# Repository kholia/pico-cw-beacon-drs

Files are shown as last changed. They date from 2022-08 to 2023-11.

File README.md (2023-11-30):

#### Details

This project generates a RF signal by toggling a GPIO pin (of a Raspberry Pi
Pico / Pico W board) at a high speed (HF frequency).

Note: The default GPIO pin is `GP2`.

#### Build Steps

Note: This repository has pre-built firmware files in it (`*.uf2` files) for
testing, and debugging purposes.

The following steps demonstrate the process of re-building the firmware from
the source code.

Common steps:

```
sudo apt install cmake gcc-arm-none-eabi libnewlib-arm-none-eabi \
    libstdc++-arm-none-eabi-newlib

sudo apt install gqrx-sdr fldigi pavucontrol pavucontrol-qt pamix
```

```
./build.sh
```

#### Customizations

To customize the CW message, CW speed, and the message, please edit the
`blink.pio` and `message.h` files.

- CW beacon message can be changed in `message.h` file.

- WPM can be changed in `blink.pio` file.

  ```
  // https://www.codebug.org.uk/learn/step/541/morse-code-timing-rules/
  int dit_delay = 92; // 13 WPM
  ```

- RF frequency can be changed in `blink.pio` file.

  The default value targets the 30m band amateur radio band.

Note: Whenever you change these files, please run the following command to
build the firmware file(s).

```
./build_again.sh
```

#### Usage

Write `pio_blink_pico.uf2` to the Raspberry Pi Pico board OR write
`pio_blink_pico_w.uf2` to the Raspberry Pi Pico W board.

To do so, press the BOOTSEL button and hold it while you connect the other end
of the micro USB cable to your computer. This puts your Raspberry Pi Pico into
USB mass storage device mode. Drag and drop the appropriate .uf2 file to the
`Pico` drive.

Attach picocom or another serial terminal program to `/dev/ttyACM0` (typically)
for added fun.

https://projects.raspberrypi.org/en/projects/getting-started-with-the-pico has
additional details on this process.

Monitor the lower 30m or 144 MHz (2m) band using a SDR for receiving the CW
beacon.

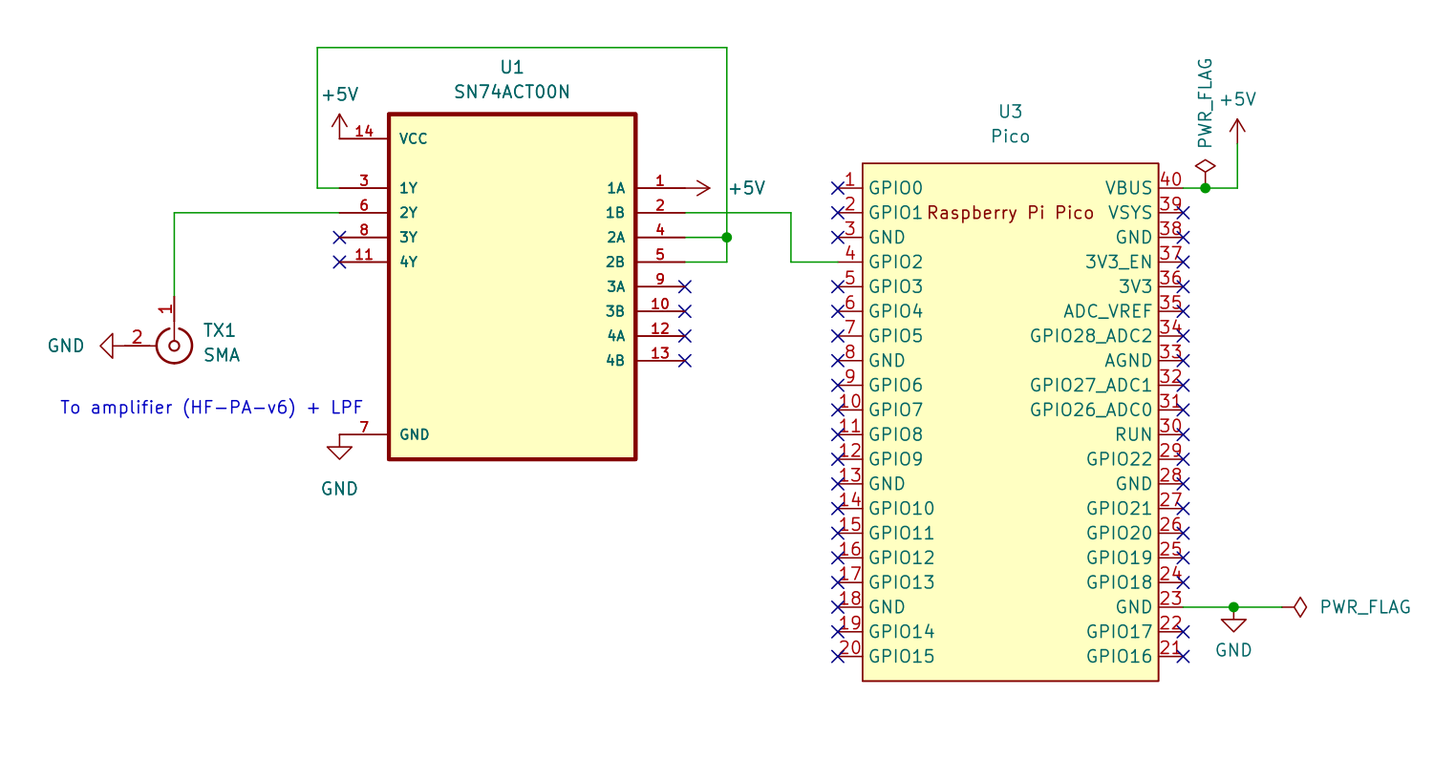
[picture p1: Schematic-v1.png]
Schematic


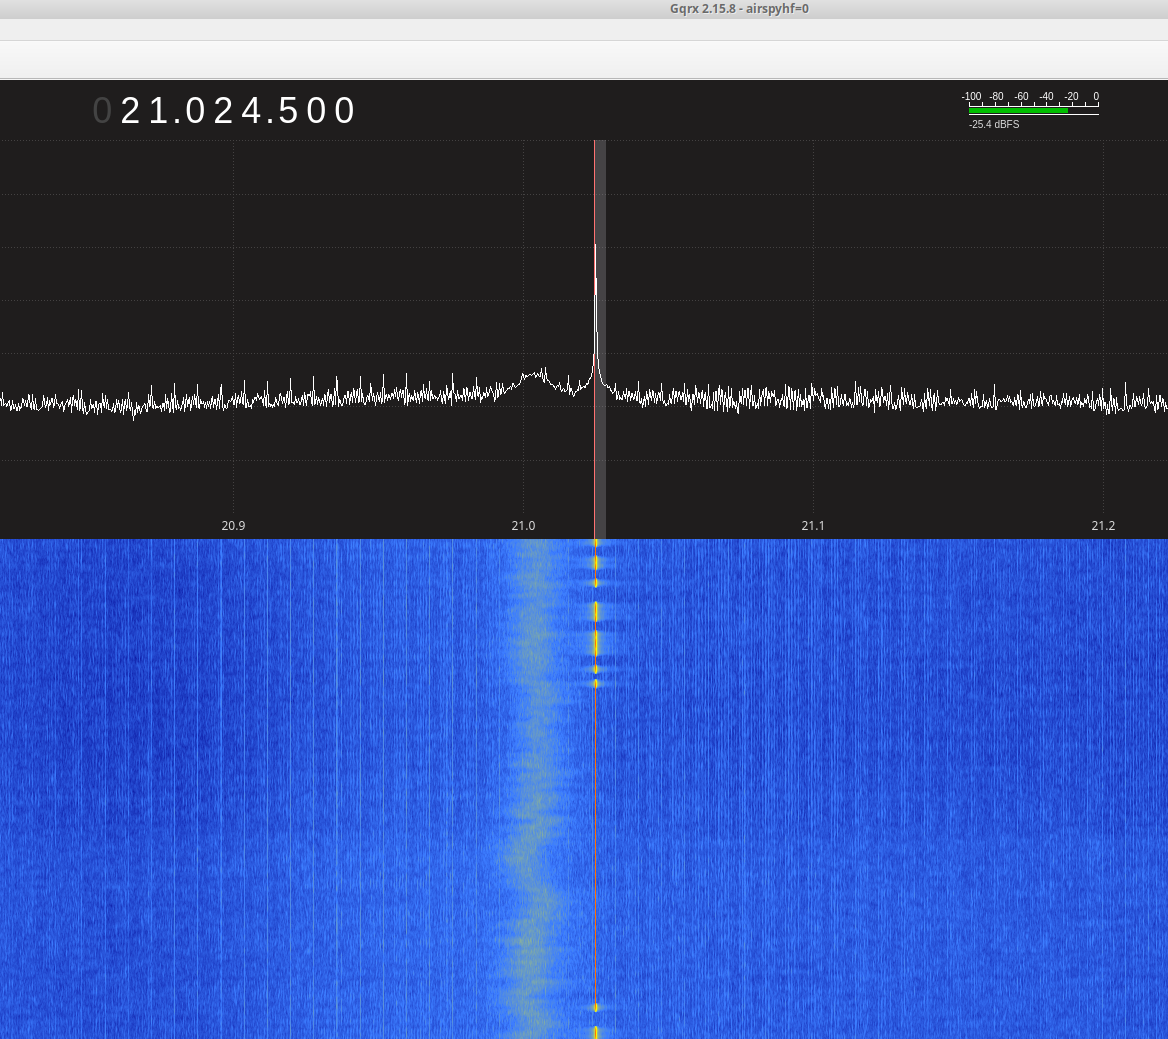
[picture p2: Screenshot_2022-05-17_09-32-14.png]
Proof - HF

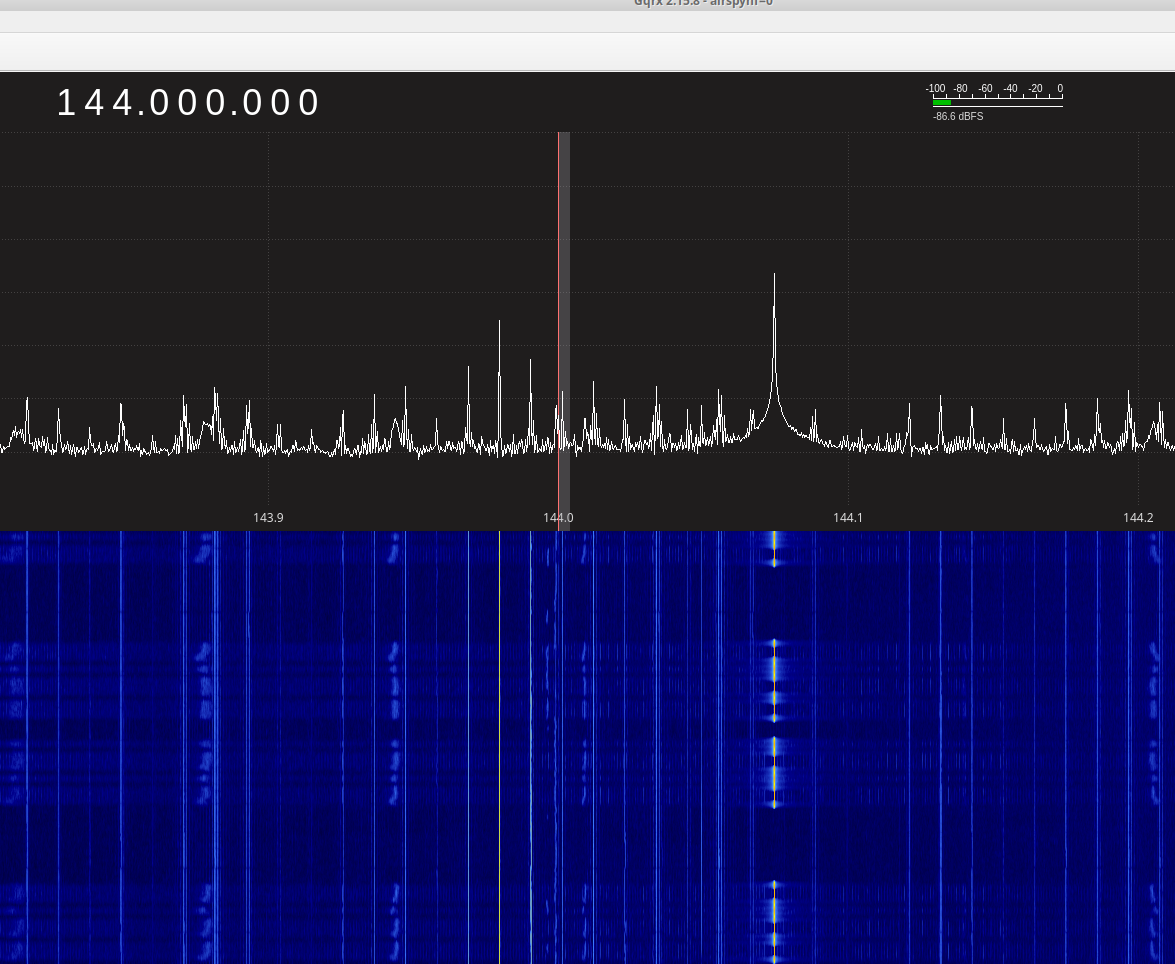
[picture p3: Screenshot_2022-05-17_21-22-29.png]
Proof - VHF


#### Amplifier Options

- [QRPp-Amplifier-v2](./QRPp-Amplifier-v2)
- [QRPp-Amplifier-v3](./QRPp-Amplifier-v3)
- https://antrak.org.tr/blog/adx-arduino-digital-transceiver/ - ADX PA

#### Future Ideas

- Implement FM modulation for the `VHF Fox`.

#### PCB Render

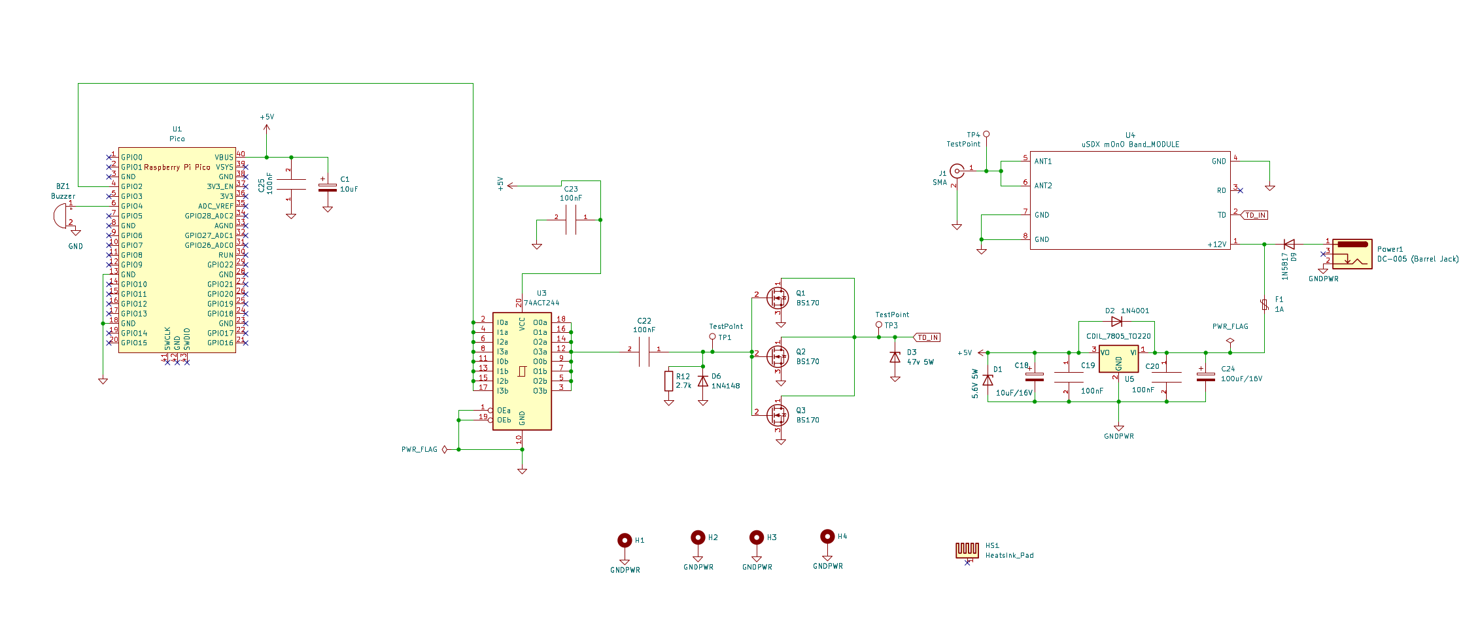
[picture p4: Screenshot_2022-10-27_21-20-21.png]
PCB Schematic

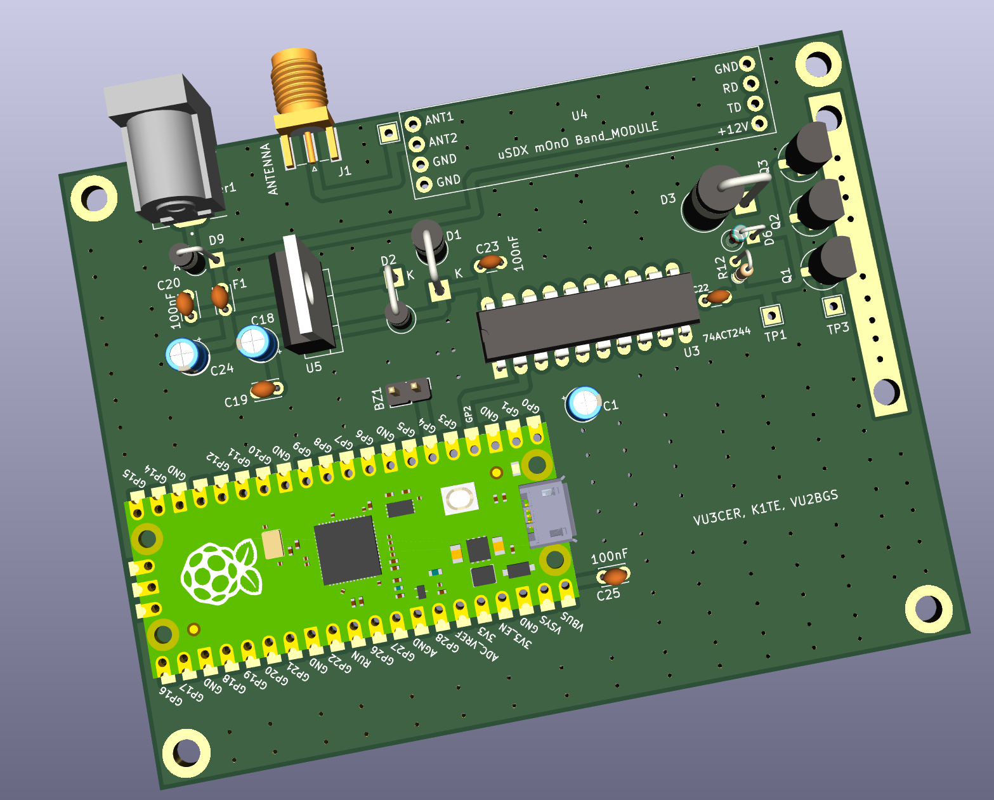
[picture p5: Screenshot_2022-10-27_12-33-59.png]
PCB Render


[UPDATE] The first version of the PCB was successfully validated on
26th-October-2022.

Output is > 3.25W (~36.2Vpp) @ 14 MHz @ 13v with the ADX LPF filter.

Use `27 SWG winding wire` in the ADX LPF filter.

#### Automatic CW Decoding

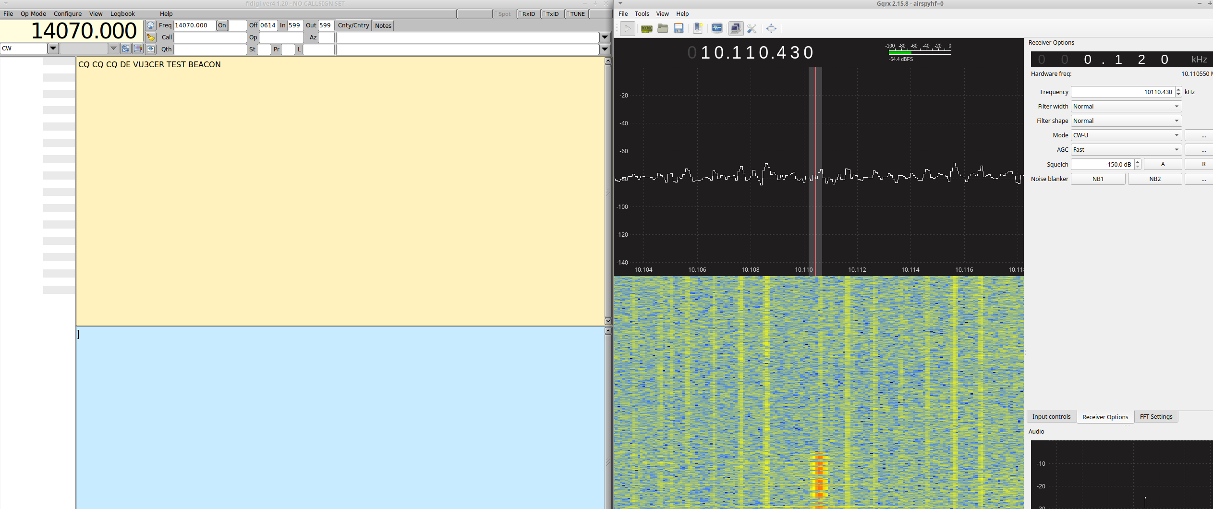
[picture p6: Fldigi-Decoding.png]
Automatic CW Decoding

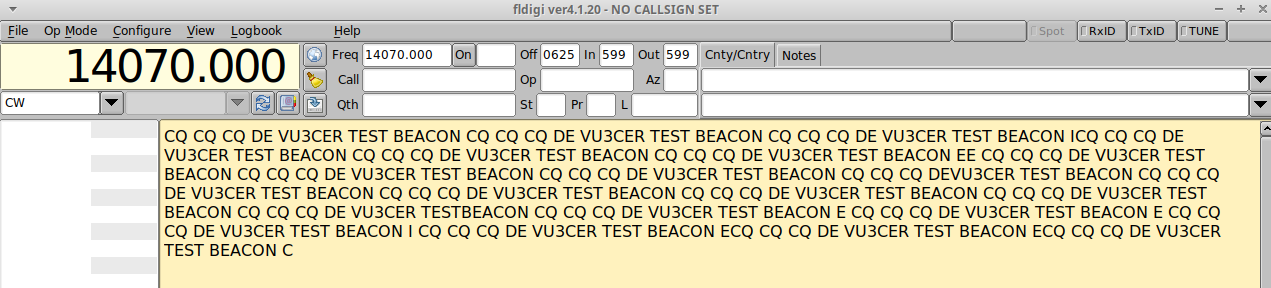
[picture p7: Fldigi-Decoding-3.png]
Automatic CW Decoding 3


Setup a virtual audio cable:

```
pacmd load-module module-null-sink sink_name=Virtual0
pacmd update-sink-proplist Virtual0 device.description=Virtual0
pacmd update-source-proplist Virtual0.monitor device.description=Virtual0
```

Ask Gqrx to output audio to this `Virtual0` device.

Use `PulseAudio` device in Fldigi.

Using `pavucontrol` redirect the Fldigi input to come from `Virtual0`. Go to
the `Recording` tab in `pavucontrol` to do this.

You are all set for automatic CW decoding using `Fldigi` software now. Set `Op
Mode` to `CW` in Fldigi.

...

On Android, you can use the `Morse Expert` app for automatic CW decoding.

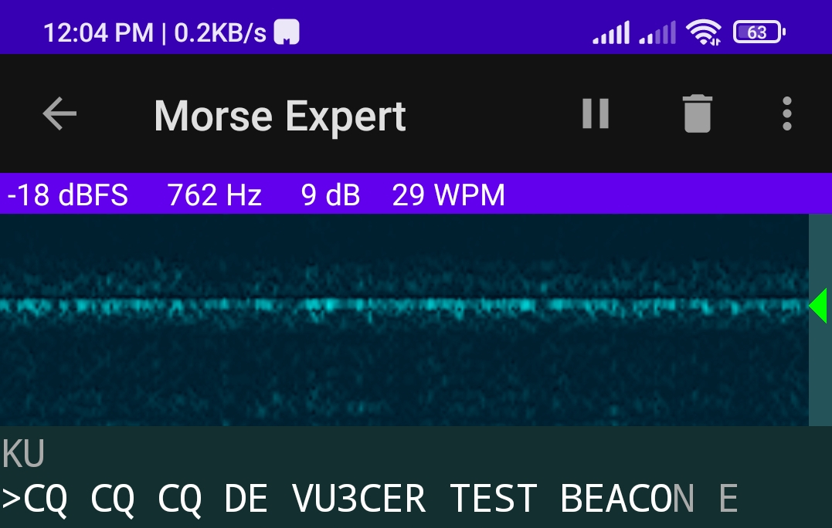
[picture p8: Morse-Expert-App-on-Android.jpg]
Morse Expert 1


#### Credits

- Bradshaw Lupton - K1TE

- Gajendra Kumar - VU2BGS

- Barb - WB2CBA

#### References

- https://github.com/raspberrypi/pico-examples/blob/master/picoboard/blinky/blinky.c
- https://antrak.org.tr/blog/adx-arduino-digital-transceiver/
- https://github.com/WB2CBA/ADX

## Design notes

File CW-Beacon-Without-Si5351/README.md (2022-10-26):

Firmware can be downloaded from https://github.com/kholia/pico-cw-beacon-drs page.

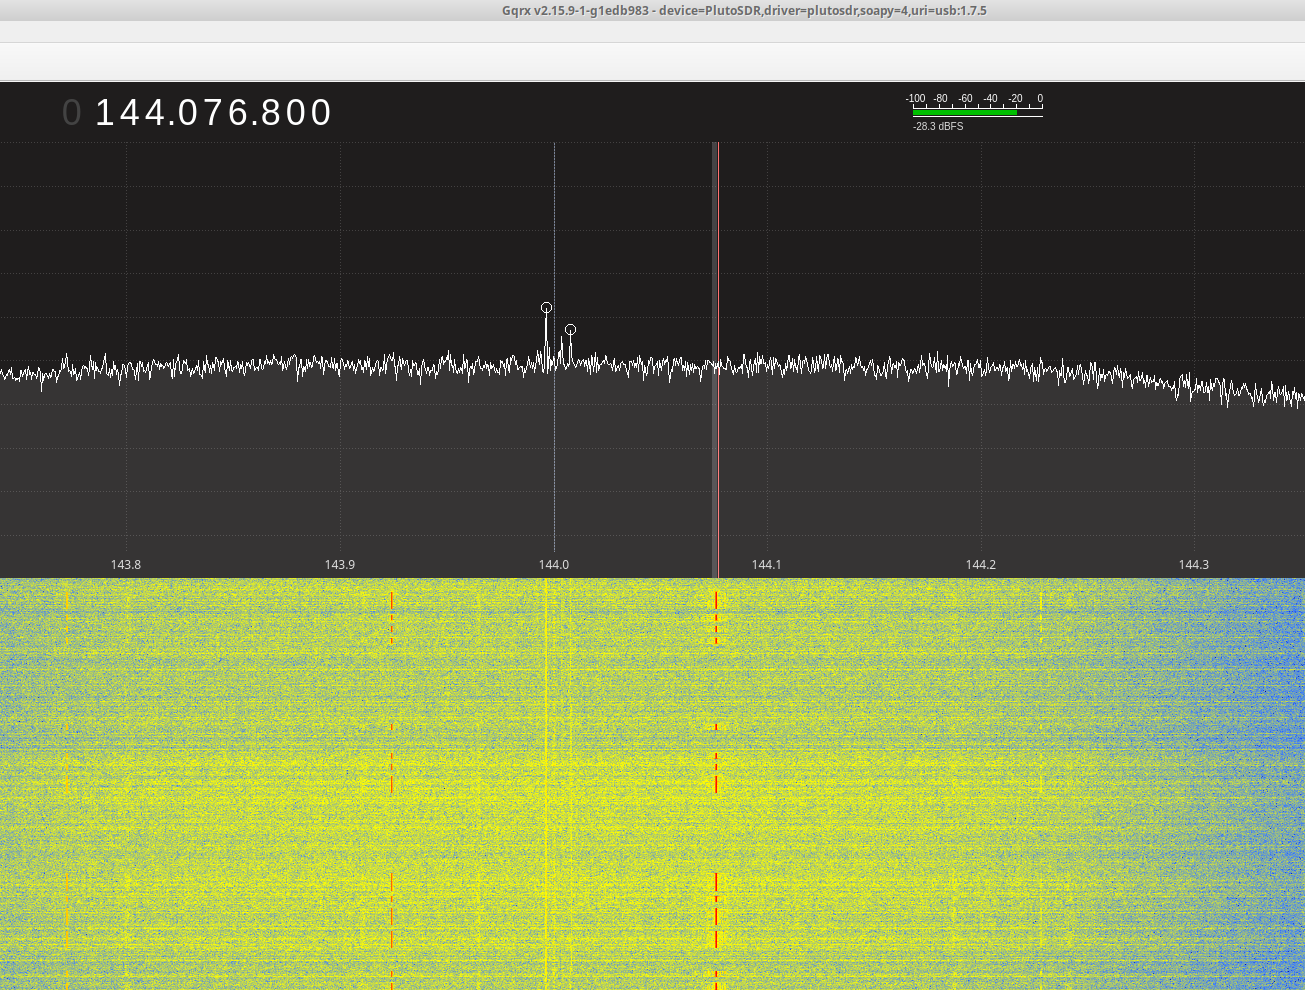
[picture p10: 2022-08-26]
Screenshot_2022-07-23_09-56-51.png

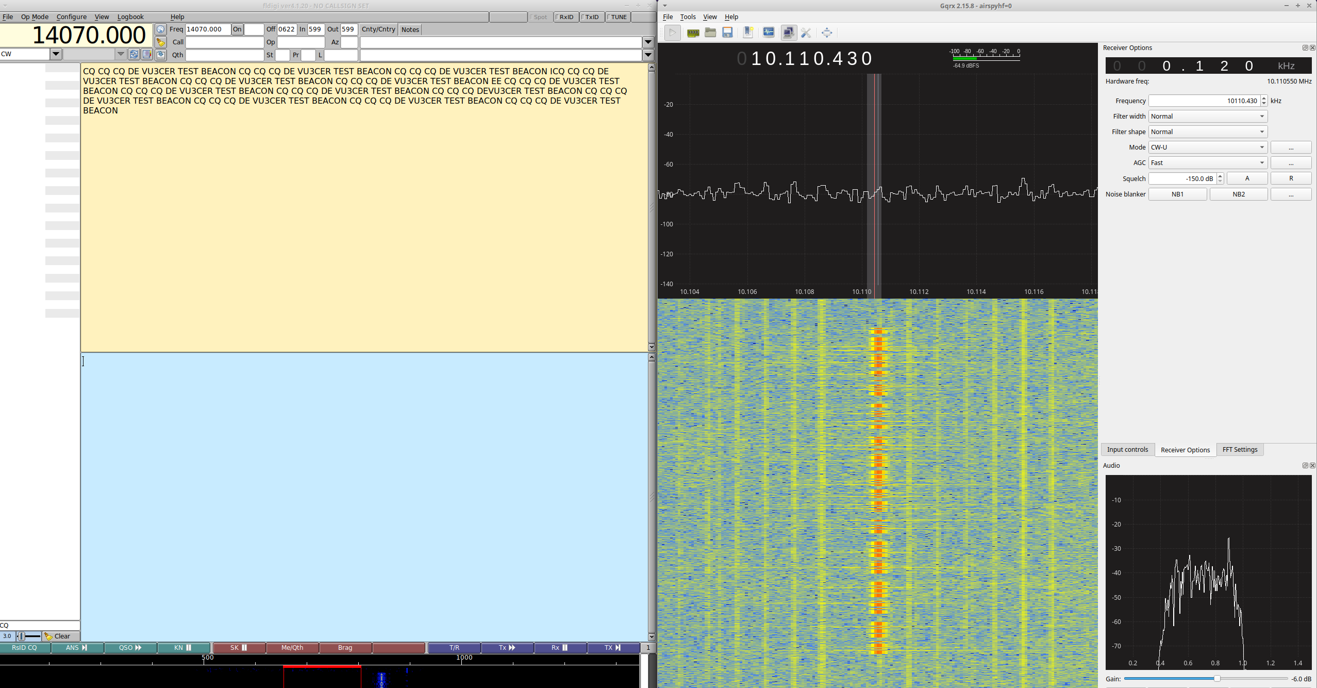
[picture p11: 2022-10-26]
Fldigi-Decoding-2.png

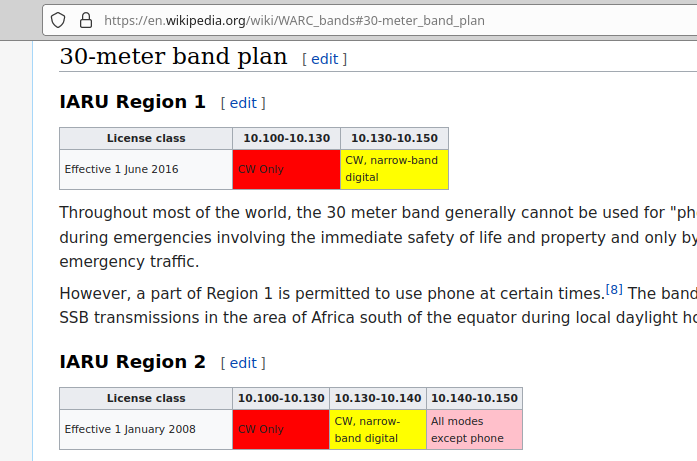
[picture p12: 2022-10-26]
30m-Screenshot_2022-09-22_09-16-28.png

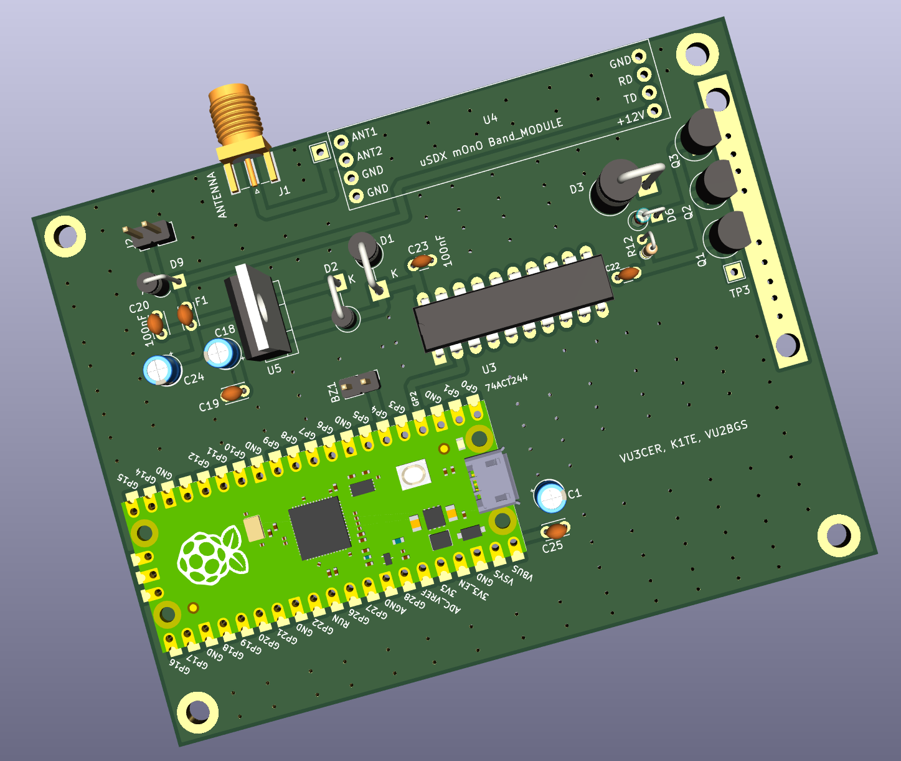
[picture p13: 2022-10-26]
Screenshot_2022-10-10_15-08-42.png

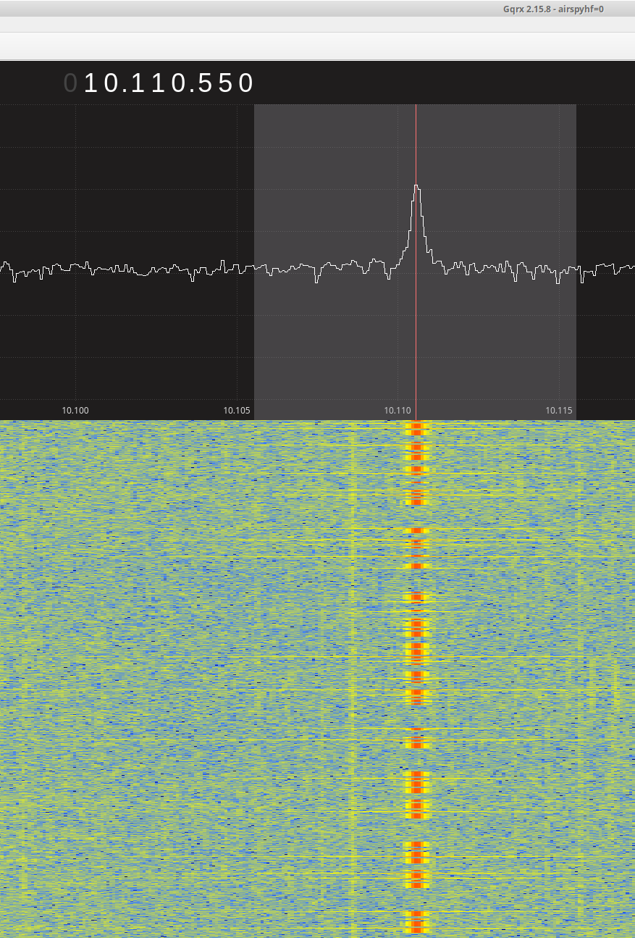
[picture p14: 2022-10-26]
30m-Screenshot_2022-09-22_09-16-50.png

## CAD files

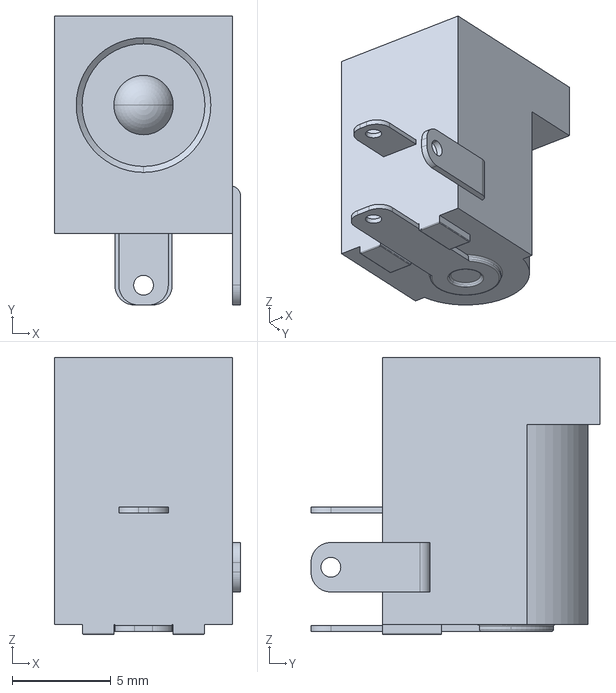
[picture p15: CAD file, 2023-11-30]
PCB/models/DC-005-5A-2.0.step
9.40 x 14.6 x 14.0 mm

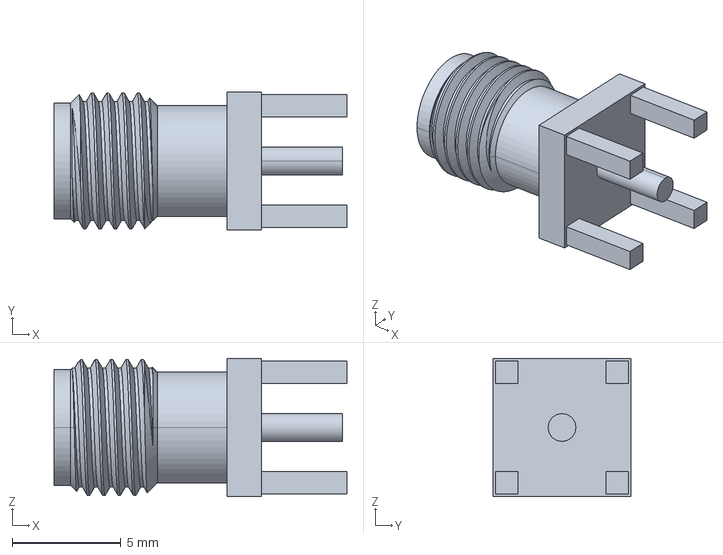
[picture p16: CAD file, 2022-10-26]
PCB/models/901-144.stp
13.5 x 6.35 x 6.35 mm

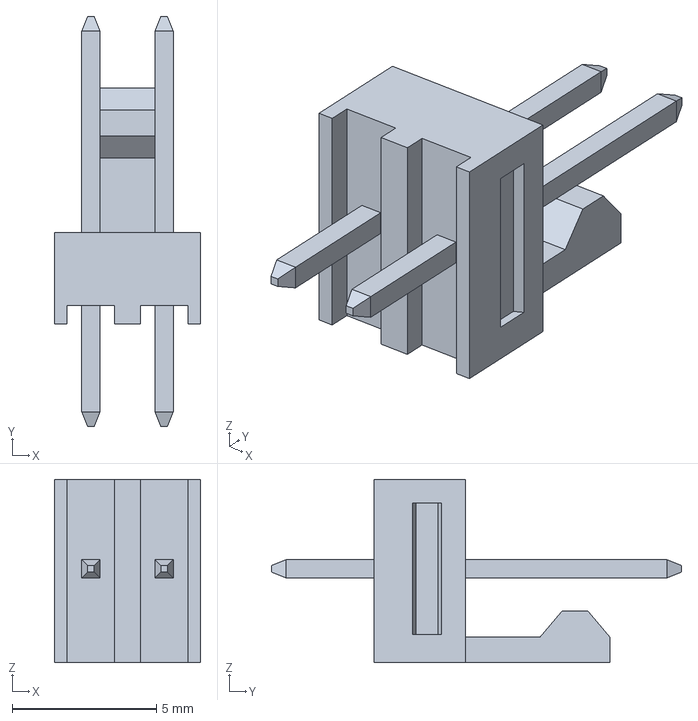
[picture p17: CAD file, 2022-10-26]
PCB/models/22-23-2021.stp
5.08 x 14.2 x 6.35 mm

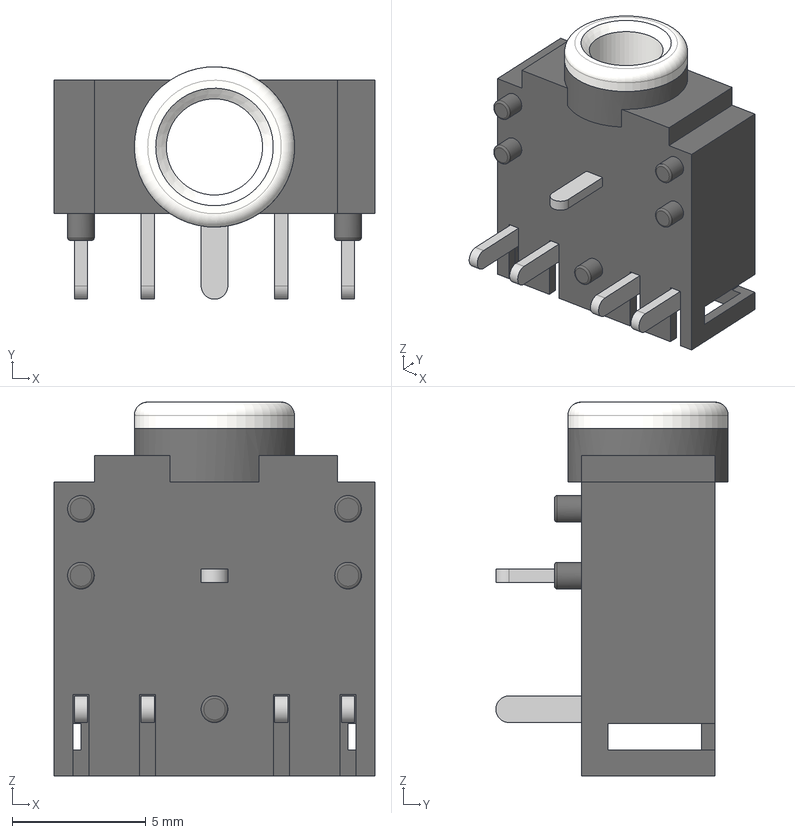
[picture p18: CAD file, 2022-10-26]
PCB/models/pj-307.step
12.0 x 8.70 x 14.0 mm

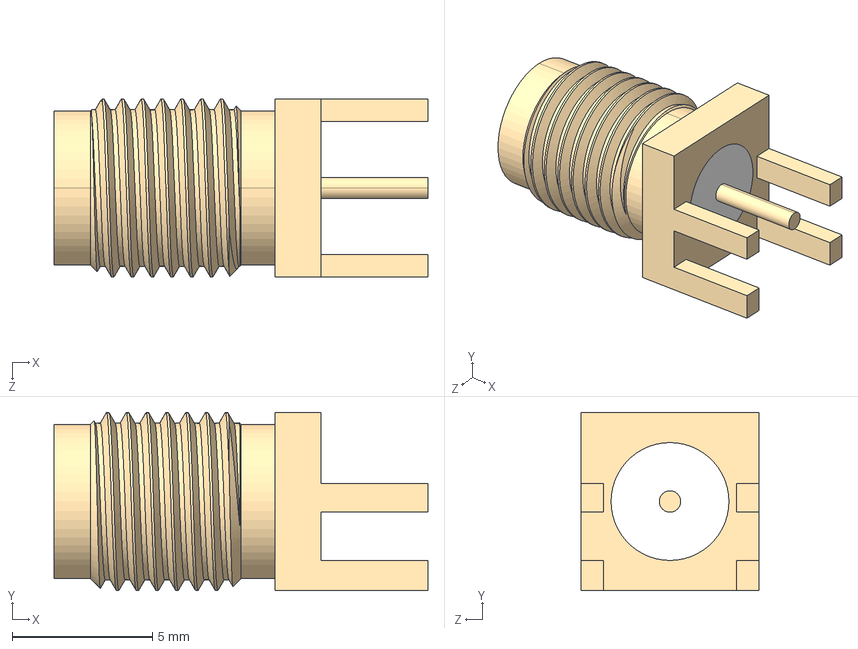
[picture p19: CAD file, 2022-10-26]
PCB/models/CON-SMA-EDGE-S--3DModel-STEP-56544.STEP
13.3 x 6.35 x 6.35 mm

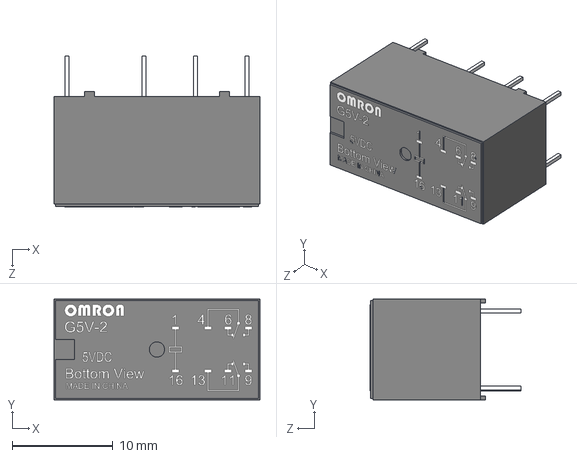
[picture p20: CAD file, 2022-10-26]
PCB/models/User Library-OMRON G5V-2.STEP
20.4 x 10.0 x 14.9 mm

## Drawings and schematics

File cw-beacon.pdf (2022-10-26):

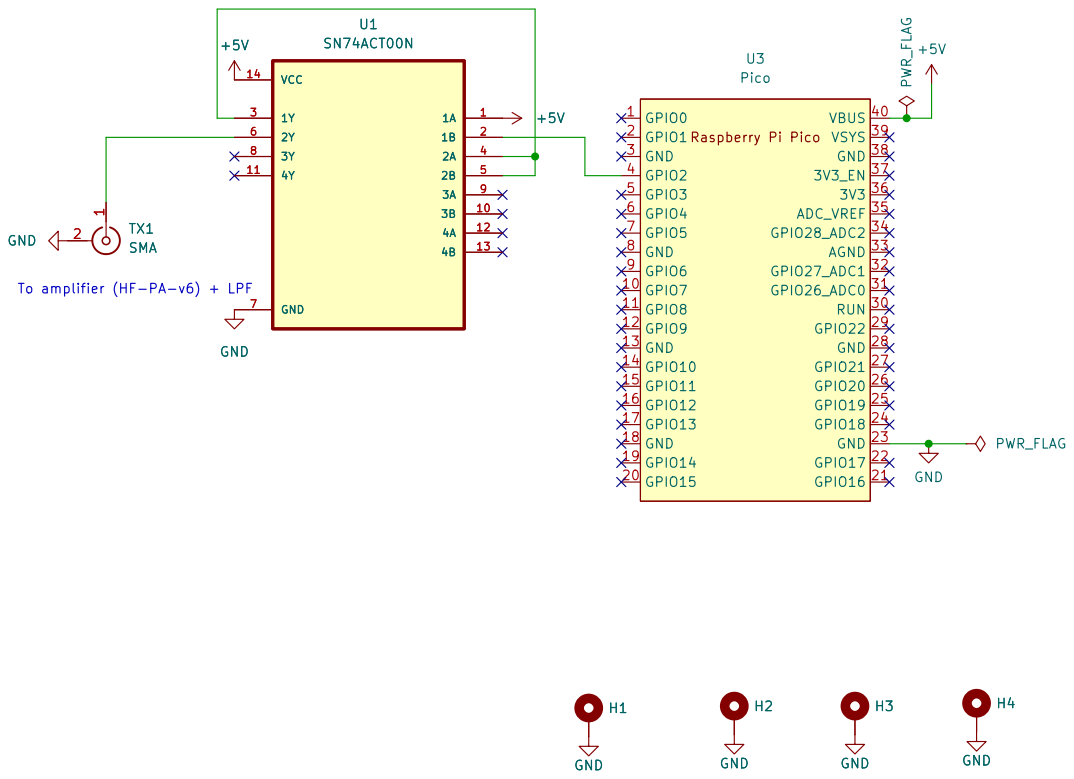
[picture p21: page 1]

File: cw-beacon.kicad_sch Sheet: / VU3CER

Id: 1/1 Title: Easy CW Beacon without Si5351

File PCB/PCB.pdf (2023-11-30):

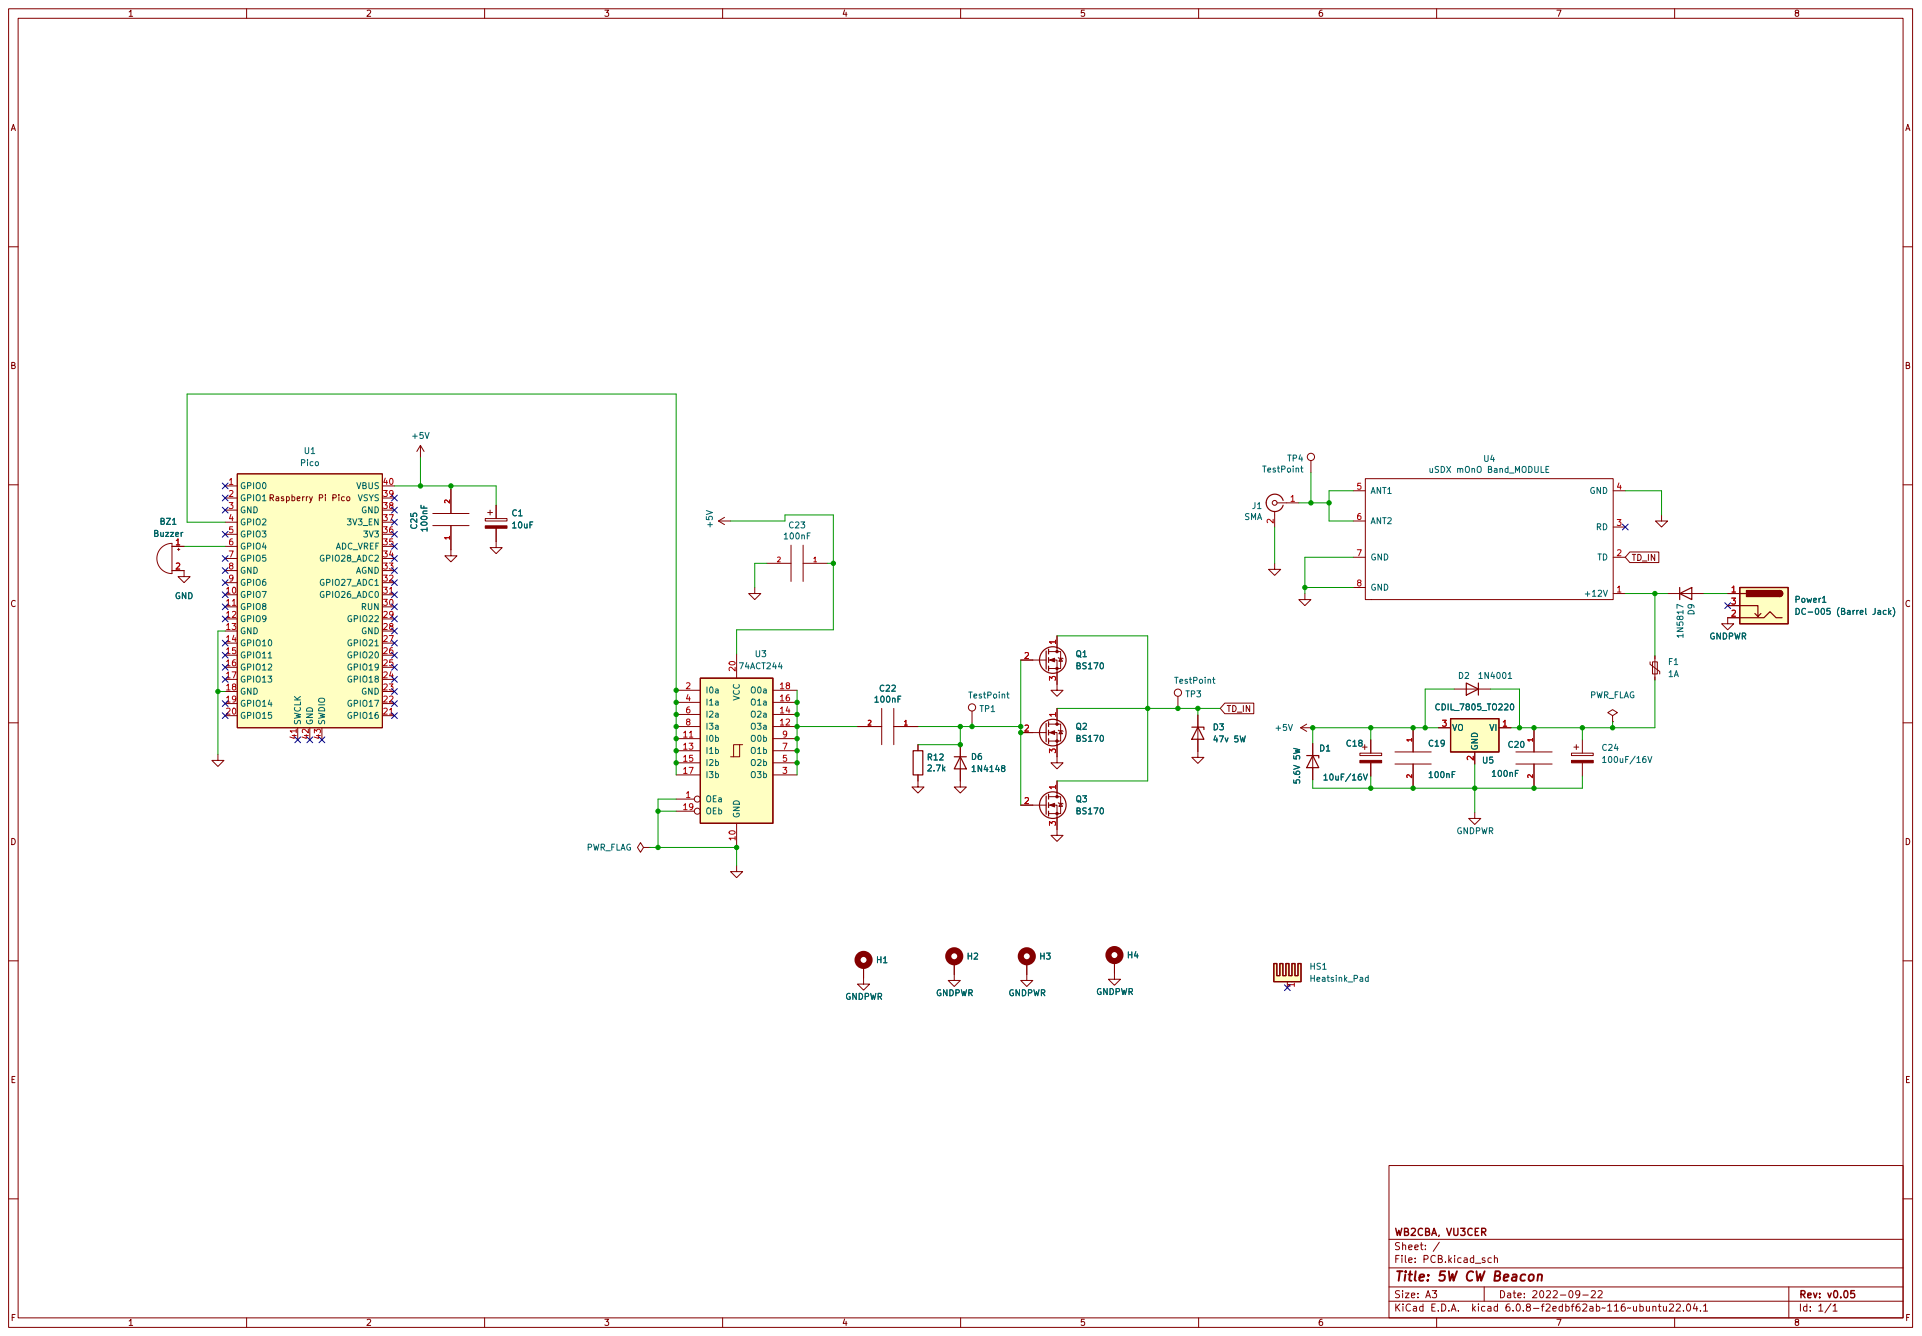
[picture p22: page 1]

2 VO 3 U5 CDIL_7805_TO220 +12V 1 TD 2 RD 3 GND 4 ANT1 5 ANT2 6 GND 7 GND 8 U4

Id: 1/1 Title: 5W CW Beacon

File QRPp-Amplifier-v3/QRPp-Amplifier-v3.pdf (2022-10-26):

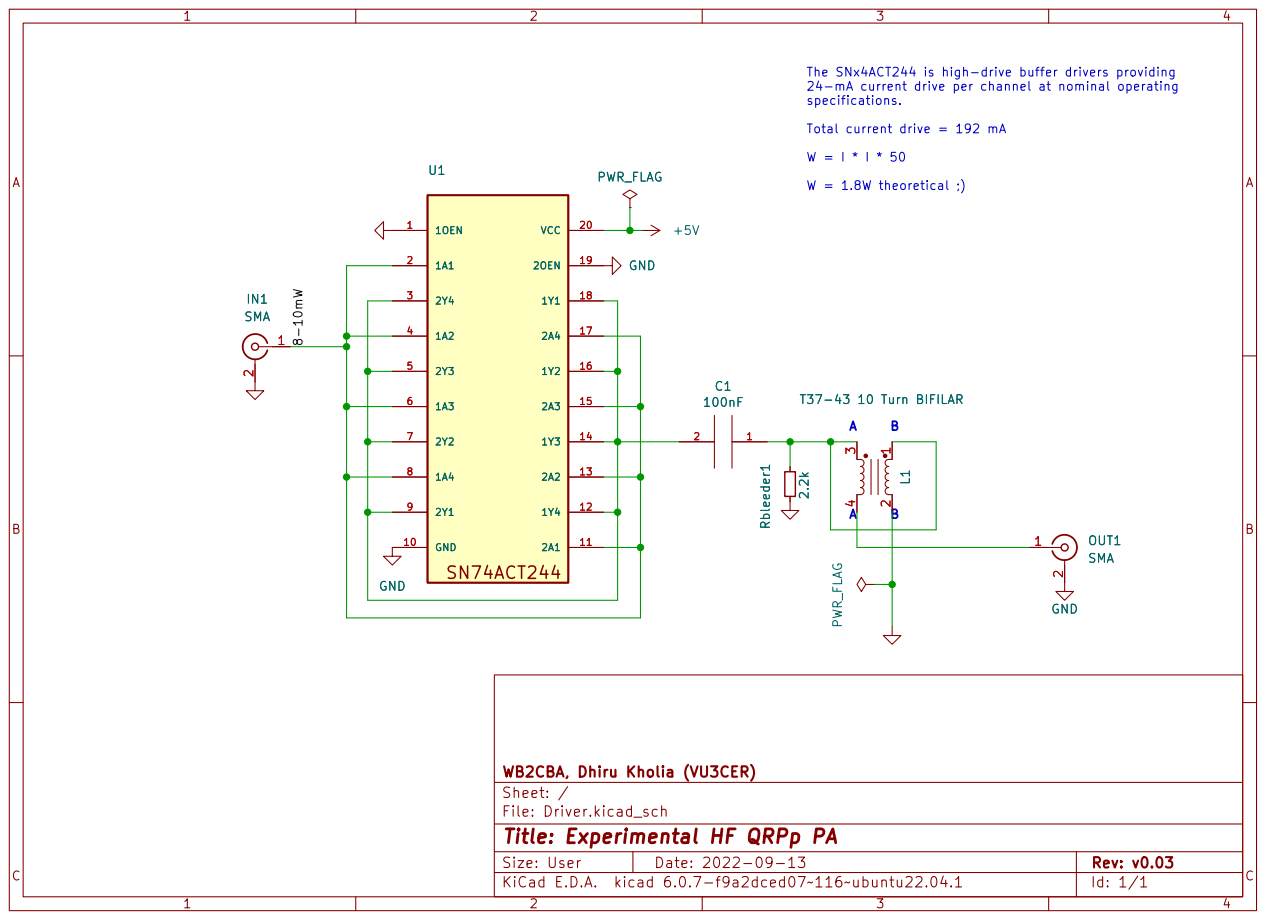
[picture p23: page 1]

The SNx4ACT244 is high-drive buffer drivers providing
24-mA current drive per channel at nominal operating

3 4 L1 T37-43 10 Turn BIFILAR GND GND

Id: 1/1 Title: Experimental HF QRPp PA

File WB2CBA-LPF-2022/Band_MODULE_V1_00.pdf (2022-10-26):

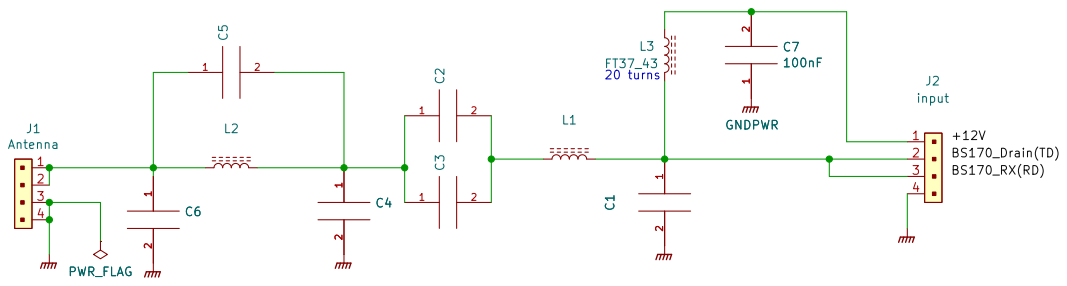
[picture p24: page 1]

Id: 1/1 Title: ADX HF TRX Band Module

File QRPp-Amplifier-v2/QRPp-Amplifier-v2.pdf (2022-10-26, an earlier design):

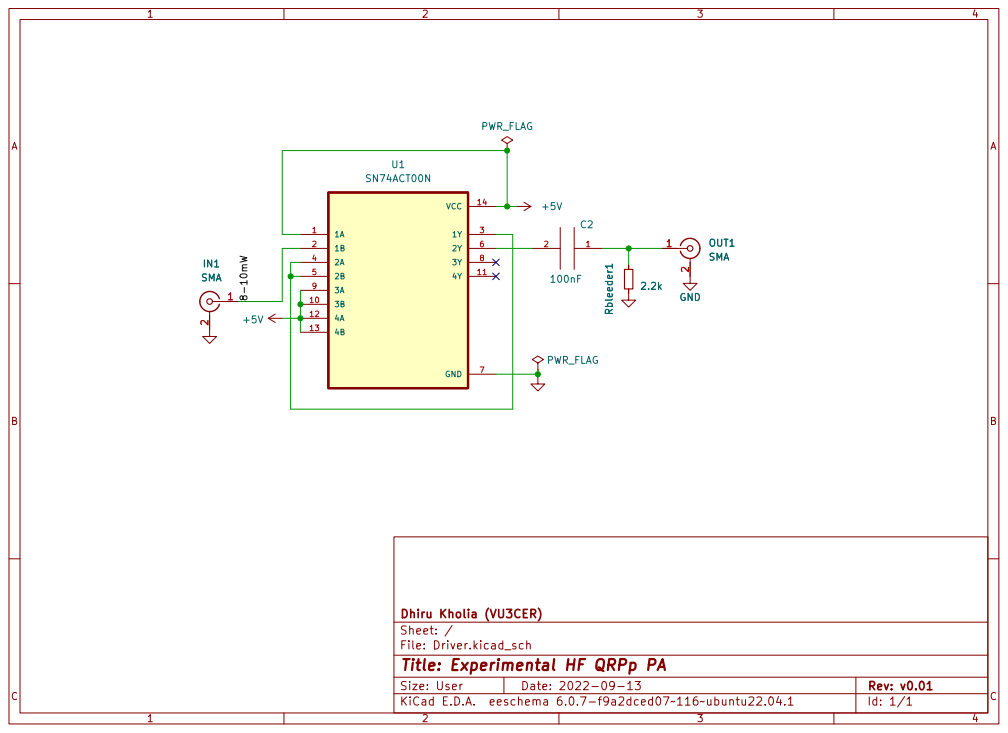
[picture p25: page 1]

File: Driver.kicad_sch Sheet: / Dhiru Kholia (VU3CER)

Id: 1/1 Title: Experimental HF QRPp PA

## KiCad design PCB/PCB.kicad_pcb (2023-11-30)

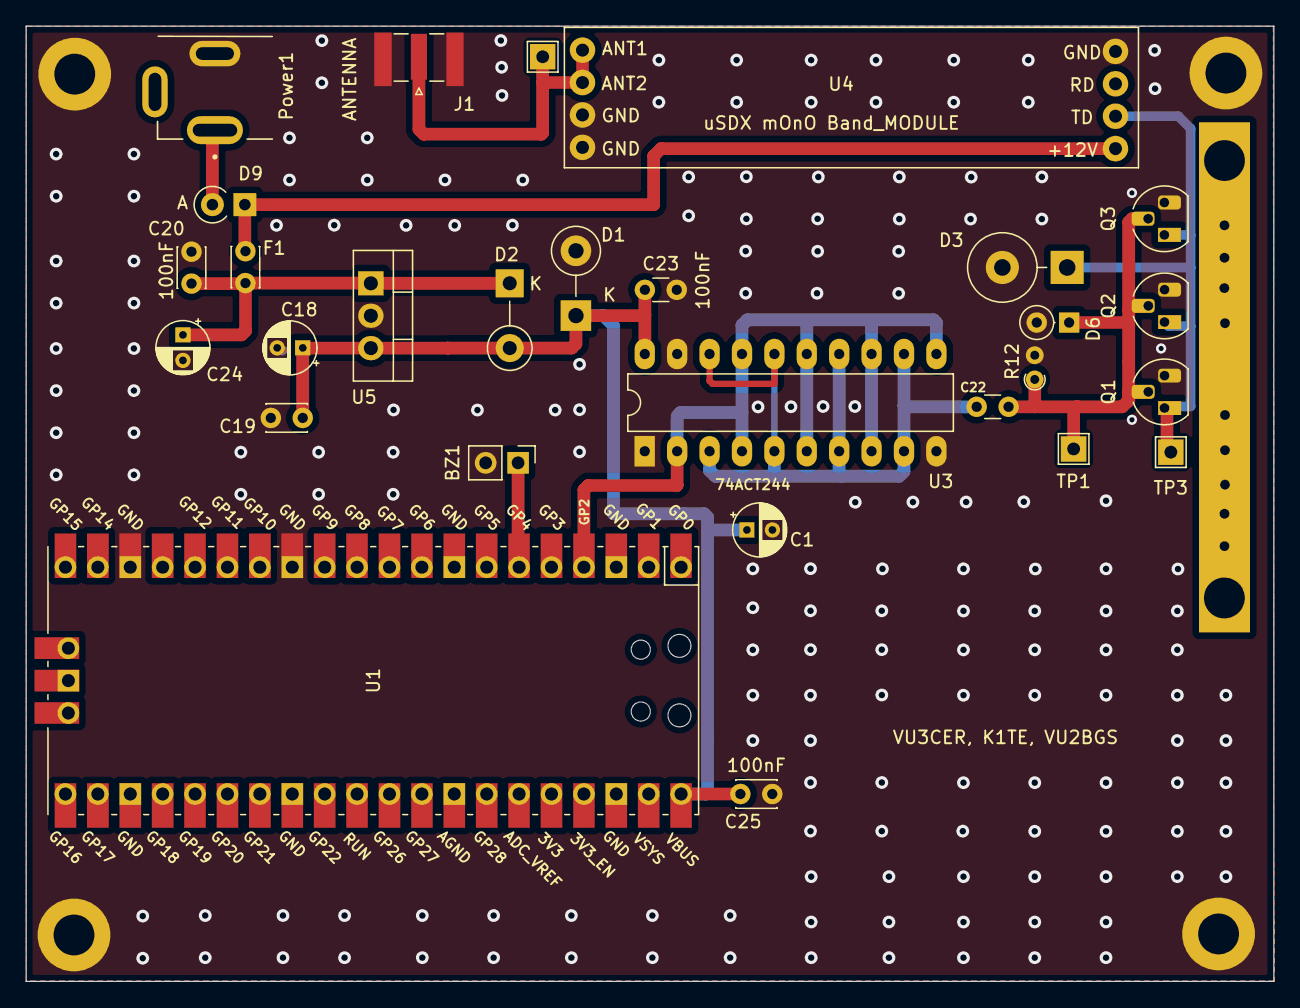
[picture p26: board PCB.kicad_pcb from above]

Board: 2 copper layers, 97.8 x 74.9 mm, 33 parts (0 on the bottom side), 11 nets.

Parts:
BZ1: Buzzer; PinHeader_1x02_P2.54mm_Vertical
C1: 10uF; CP_Radial_D4.0mm_P2.00mm
C18: 10uF/16V; CP_Radial_D4.0mm_P2.00mm
C19, C20, C25: 100nF; C_Disc_D3.0mm_W2.0mm_P2.50mm
C22, C23: 100nF; C_Disc_D3.0mm_W1.6mm_P2.50mm
C24: 100uF/16V; CP_Radial_D4.0mm_P2.00mm
D1: 5.6V 5W; D_DO-15_P5.08mm_Vertical_KathodeUp
D2: 1N4001; D_DO-41_SOD81_P5.08mm_Vertical_KathodeUp
D3: 47v 5W; D_DO-201_P5.08mm_Vertical_KathodeUp
D6: 1N4148; D_DO-35_SOD27_P2.54mm_Vertical_KathodeUp
D9: 1N5817; D_A-405_P2.54mm_Vertical_KathodeUp
F1: 1A; C_Disc_D3.0mm_W2.0mm_P2.50mm
H1, H2, H3, H4: MountingHole_Pad; MountingHole_3.2mm_M3_ISO7380_Pad
HS1: Heatsink_Pad; ThermalPad_Final
J1: SMA; SMA_Samtec_SMA-J-P-X-ST-EM1_EdgeMount
Power1: DC-005 (Barrel Jack); XKB_DC-005-5A-2.0_Modded
Q1, Q2, Q3: BS170; TO-92_HandSolder
R12: 2.7k; R_Axial_DIN0204_L3.6mm_D1.6mm_P1.90mm_Vertical
TP1, TP3, TP4: TestPoint; TestPoint_THTPad_2.0x2.0mm_Drill1.0mm
U1: Pico; RPi_Pico_SMD_TH
U3: 74ACT244; DIP-20_W7.62mm_LongPads
U4: uSDX mOnO Band_MODULE; uSDX_LPF_Band_Module
U5: CDIL_7805_TO220; TO-220-3_Vertical

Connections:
+5V: C1.1, C18.1, C19.1, C23.1, C25.2, D1.1 (K), D2.2 (A), U1.40 (VBUS), U3.20 (VCC), U5.3 (VO)
GND: BZ1.2 (+), C1.2, C18.2, C19.2, C20.2, C23.2, C24.2, C25.1, D1.2 (A), D3.2 (A), D6.2 (A), H1.1, H2.1, H3.1, H4.1, J1.2 (Ext), Power1.2, Q1.3 (S), Q2.3 (S), Q3.3 (S), R12.2, U1.13 (GND), U1.18 (GND), U3.1 (OEa), U3.10 (GND), U3.19 (OEb), U4.4 (GND), U4.7 (GND), U4.8 (GND), U5.2 (GND)
unnamed: BZ1.1 (-), U1.6 (GPIO4)
unnamed: C20.1, C24.1, D2.1 (K), F1.2, U5.1 (VI)
unnamed: C22.1, D6.1 (K), Q1.2 (G), Q2.2 (G), Q3.2 (G), R12.1, TP1.1
unnamed: C22.2, U3.3 (O3b), U3.5 (O2b), U3.7 (O1b), U3.9 (O0b), U3.12 (O3a), U3.14 (O2a), U3.16 (O1a), U3.18 (O0a)
unnamed: D9.1 (K), F1.1, U4.1 (+12V)
unnamed: D9.2 (A), Power1.1
unnamed: J1.1 (In), TP4.1, U4.5 (ANT1), U4.6 (ANT2)
unnamed: U1.4 (GPIO2), U3.2 (I0a), U3.4 (I1a), U3.6 (I2a), U3.8 (I3a), U3.11 (I0b), U3.13 (I1b), U3.15 (I2b), U3.17 (I3b)
TD_IN: D3.1 (K), Q1.1 (D), Q2.1 (D), Q3.1 (D), TP3.1, U4.2 (TD)

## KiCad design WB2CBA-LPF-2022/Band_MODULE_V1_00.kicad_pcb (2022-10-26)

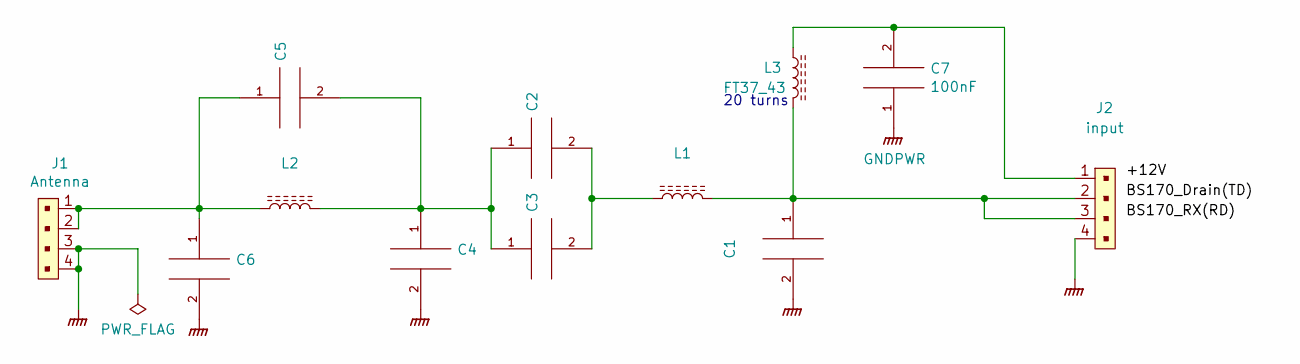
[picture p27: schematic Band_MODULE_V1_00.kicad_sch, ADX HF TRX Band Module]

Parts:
C1, C2, C3, C4, C5, C6: C_Disc_D5.0mm_W2.5mm_P2.50mm
C7: 100nF; C_Disc_D5.0mm_W2.5mm_P2.50mm
J1: Antenna; PinHeader_1x4_P2.54mm_Drill1.02mm; MPN 0022232041; Digi-Key_PN WM4202-ND
J2: input; PinHeader_1x4_P2.54mm_Drill1.02mm; MPN 0022232041; Digi-Key_PN WM4202-ND
L1, L2: L_Toroid_Vertical_L10.0mm_W5.0mm_P5.08mm
L3: FT37_43; L_Toroid_Vertical_L10.0mm_W5.0mm_P5.08mm

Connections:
GNDPWR: C1.2, C4.2, C6.2, C7.1, J1.3, J1.4, J2.4
unnamed: C1.1, J2.2, J2.3, L1.2, L3.2
unnamed: C2.1, C3.1, C4.1, C5.2, L2.2
unnamed: C2.2, C3.2, L1.1
unnamed: C5.1, C6.1, J1.1, J1.2, L2.1
unnamed: C7.2, J2.1, L3.1

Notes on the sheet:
20 turns

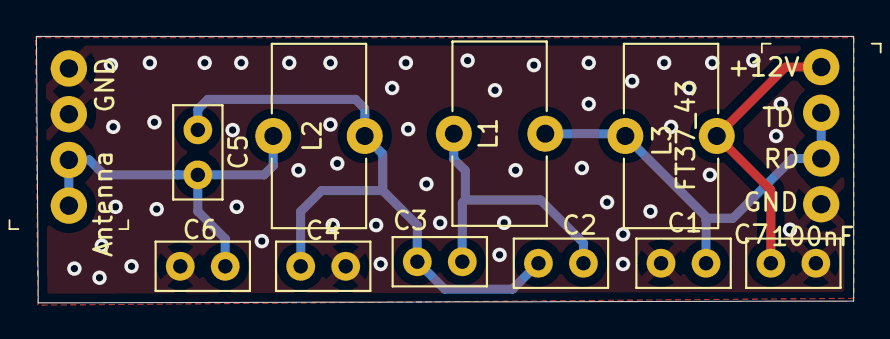
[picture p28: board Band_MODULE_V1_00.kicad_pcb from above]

Board: 2 copper layers, 45.4 x 14.8 mm, 12 parts (0 on the bottom side), 6 nets.

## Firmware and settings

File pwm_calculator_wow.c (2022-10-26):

// Credits: https://forums.raspberrypi.com/ (hippy)

#include "stdio.h"
#include "stdint.h"

// Set DUTY to zero to maximise 'top'
// Set DUTY to 1 for maximum frequency accuracy
// Set DUTY to what the max duty value is, for example 100 for 0 to 100

#define DUTY    1                   // Maximum accuracy

#define TOP_MAX 65534
#define DIV_MIN ((0x01 << 4) + 0x0) // 0x01.0
#define DIV_MAX ((0xFF << 4) + 0xF) // 0xFF.F
// #define CLOCK   125000000
#define CLOCK   250000000

int Better(uint32_t clock, float freq, uint32_t duty,
           uint32_t now_top, uint32_t now_div,
           uint32_t try_top, uint32_t try_div) {
  // If what we are trying cannot be achieved it's not better
  if ((try_top == 0) || (try_top > (TOP_MAX + 1))) {
    return 0;
  }
  // If we haven't got anything yet this must be better
  if (now_top == 0) {
    return 1;
  }
  // If we don't have enough steps we aren't better unless there are
  // more steps than we currently have
  if ((try_top < (duty - 1)) && (try_top <= now_top)) {
    return 0;
  }
  // Determine if what we already have is good enough
  float now_frq = (float)(clock << 4) / now_div / (now_top + 1);
  float now_gap = now_frq - freq;
  //  Using 'abs' doesn't work on a Pi, screws the outcome, so do it manually
  if (now_gap < 0.0) {
    now_gap = -now_gap;
  }
  // If good enough then nothing is better
  if (now_gap == 0.0) { // or '<= 0.0001' if we don't mind some inaccuracy
    return 0;
  }
  // Determine if what we are trying is better than what we have
  float try_frq = (float)(clock << 4) / try_div / (try_top + 1);
  float try_gap = try_frq - freq;
  //  Using 'abs' doesn't work on a Pi, screws the outcome, so do it manually
  if (try_gap < 0.0) {
    try_gap = -try_gap;
  }
  // We judge best on percentage error of output frequency to wanted
  float now_pct = now_gap * 100.0 / freq;
  float try_pct = try_gap * 100.0 / freq;
  /*
    if (try_pct < now_pct) {
      printf("%d %x %f better than %d %x %f\n", try_top, try_div, try_frq,
                                                now_top, now_div, now_frq);
    }
  */
  return try_pct < now_pct;
}

void SetPwmFreq(float freq, uint32_t duty) {
  uint32_t clock = CLOCK;
  uint32_t period;
  // Determine a div to get the frequency we want
  uint32_t div = (clock << 4) / freq / (TOP_MAX + 1);
  // e cannot use a div less than the minimum
  if (div < DIV_MIN) {
    div = DIV_MIN;
  }
  // If duty is zero then we want something with the highest top value
  // and don't care if the frequency is inaccurate.
  if (duty == 0) {
    // Determine what period the chosen div gives us
    period = (clock << 4) / div / freq;
    // We may have had a rounding error when calculating div so it may
    // be lower than it should be, which in turn causes the period to
    // be higher than it should be, higher than can be used. In which
    // case we increase the div until the period becomes usable.
    while ((period > (TOP_MAX + 1)) && (div <= DIV_MAX)) {
      period = (clock << 4) / ++div / freq;
    }
  } else {
    // We have a non-zero duty value so we are after frequency accuracy
    // but still want to have as many steps as duty has specified.
    uint32_t top = 0;  // Force the first 'Better()' to be true
    uint32_t try_top;
    uint32_t try_div = div;
    while ( try_div < DIV_MAX) {
      // Determine the top our div would give us
      try_top = ((clock << 4) / try_div / freq) - 1;
      // Try with a perfect or rounded-down top
      if (Better(clock, freq, duty, top, div, try_top, try_div)) {
        top = try_top;
        div = try_div;
      }
      // Try with a rounded-up top
      if (Better(clock, freq, duty, top, div, try_top + 1, try_div)) {
        top = try_top + 1;
        div = try_div;
      }
      try_div++;
    }
    // Rest of the code uses period so provide it
    period = top + 1;
  }
  // Check if the result is usable
  if (period <= 1) {
    printf("Freq below is too high ...\n");
  } else if (div > DIV_MAX) {
    printf("Freq below is too low ...\n");
  }
  // Determine what output frequency that will generate
  float out = (float)(clock << 4) / div / period;
  // Determine how much error that gives us
  float err = (out - freq) * 100.0 / freq;
  // Report the results
  printf("Freq = %f\t",         freq);
  printf("Top = %u\t",          period - 1);
  printf("Div = 0x%02X.%X\t",   div >> 4, div & 0xF);
  printf("Out = %f\t",          out);
  printf("Err = %f%%\n",        err);
}

int main(void) {
  uint32_t hz = CLOCK;

  // For FM modulation
  SetPwmFreq((float)14000000, DUTY);
  SetPwmFreq((float)14010000, DUTY);

  SetPwmFreq((float)50, DUTY);

  SetPwmFreq((float)1000.0, DUTY);
  SetPwmFreq((float)1006.25, DUTY);
  SetPwmFreq((float)1012.50, DUTY);
  SetPwmFreq((float)1018.75, DUTY);
  SetPwmFreq((float)1025.00, DUTY);
  SetPwmFreq((float)1031.25, DUTY);
  SetPwmFreq((float)1037.50, DUTY);
  SetPwmFreq((float)1043.75, DUTY);

  while (hz > 7) {
    if (hz <= 16) {
      SetPwmFreq((float)hz, DUTY);
      hz = hz - 1;
    } else {
      SetPwmFreq((float)((hz >> 1) * 3), DUTY);
      SetPwmFreq((float)hz, DUTY);
      hz = hz >> 1;
    }
  }
  // SetPwmFreq((float)91551, DUTY);
}

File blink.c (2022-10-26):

/**
 * Copyright (c) 2020 Raspberry Pi (Trading) Ltd.
 *
 * SPDX-License-Identifier: BSD-3-Clause
 */

#include <stdio.h>

#include "pico/stdlib.h"
#include "hardware/pio.h"
#include "hardware/clocks.h"
#include "blink.pio.h"
#include "message.h"

#ifdef RASPBERRYPI_PICO_W
#include "pico/cyw43_arch.h"
#endif

void blink_pin_forever(PIO pio, uint sm, uint offset, uint pin, unsigned char *message);

#define LED_PIN 25

int main_on() {
#ifdef RASPBERRYPI_PICO_W
    cyw43_arch_gpio_put(CYW43_WL_GPIO_LED_PIN, 1);
#else
    gpio_put(LED_PIN, 1);
#endif
}

int main_off() {
#ifdef RASPBERRYPI_PICO_W
    cyw43_arch_gpio_put(CYW43_WL_GPIO_LED_PIN, 0);
#else
    gpio_put(LED_PIN, 0);
#endif
}

int main() {
    stdio_init_all();
    set_sys_clock_khz(250000, true);
    // set_sys_clock_khz(290400, true); // required for VHF, doesn't work on Pico W apparently
    setup_default_uart();

    sleep_ms(12000); // wait for a bit before starting the beacon
    printf("\nPicoW-CW-Beacon - VU3CER and K1te@piRshared.org - September 2022\n");
    sleep_ms(3000);

#ifdef RASPBERRYPI_PICO_W
    cyw43_arch_init();
    printf("Wireless initialized!\n");
#endif

    PIO pio = pio0;
    uint offset = pio_add_program(pio, &blink_program);
    printf("Loaded program at %d\n", offset);

    gpio_set_drive_strength(2, GPIO_DRIVE_STRENGTH_12MA);

    blink_pin_forever(pio, 0, offset, 2, message);
}

// https://morsecode.world/international/timing.html
// http://www.kent-engineers.com/codespeed.htm
// 13 words-per-minute is one element every 92.31 milliseconds.
void blink_pin_forever(PIO pio, uint sm, uint offset, uint pin, unsigned char *message) {
    blink_program_init(pio, sm, offset, pin, message);
    pio_sm_set_enabled(pio, sm, true);
}

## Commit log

2022-10-26 Make HF CW Beacon on 30m band the default
    [22-23-2021.stp, 901-144.stp, Band_MODULE_V1_00.kicad_pcb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]
2023-11-30 PCB v2 - minor tweaks
    [DC-005-5A-2.0.step, PCB.kicad_pcb, PCB.kicad_sch]
